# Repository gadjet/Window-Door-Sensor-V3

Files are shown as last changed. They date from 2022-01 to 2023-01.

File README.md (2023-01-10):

# Window-Door-Sensor-V3
Smaller version of version 2.
This version has the components on one side and the ESP12 Module on the other side the PCB tracks supplying the
ESP module have also been beefed up to redice the size  of the supply capacitor and I have this  running currently
without a 1000uF capacitorand it works fine but when I tested version 2 with an oscilloscope on the supply pins of
the ESP a 220uF was enough to hold the  supply during transmission above 3V.

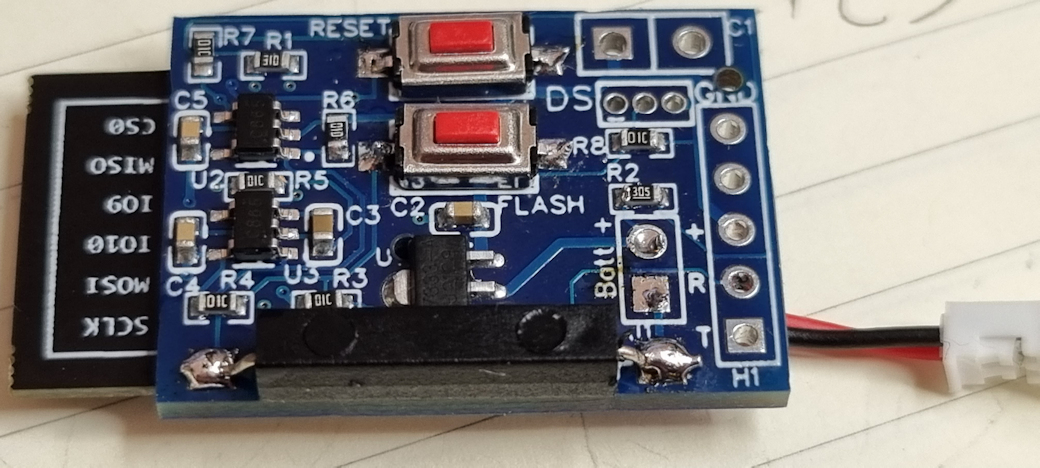
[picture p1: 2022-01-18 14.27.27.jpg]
Version 2

This version also has a DS18B20 footprint on the PCB but unfortunately I made a schoolboy error and connected the DQ
to GPIO9 which I later found out is a no-no as it's connected to the internal flash memory and accessing it causes
the ESP to crash.  If you wish to use a DS18B20 then I would cut the track to GPIO9 and run a wire from the left side
of R8 to GPIO2 on the ESP module.

If anyone is interested in buying the PCB then let  me know as I'm considering creating a Tindie store to sell
my surplus PCBs on to fund the next PCBs :-)

The code for the Sensor can be found in the earlier version

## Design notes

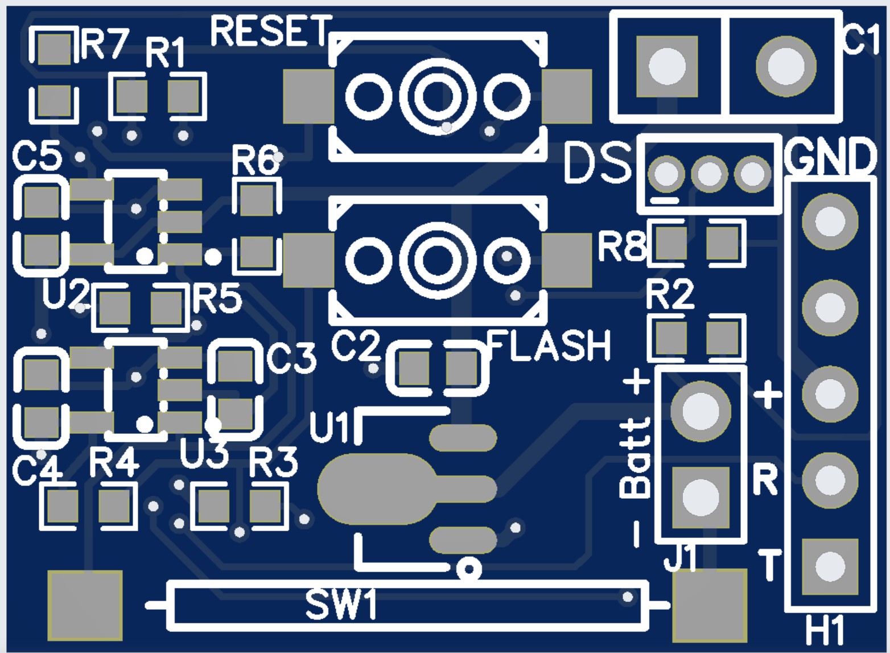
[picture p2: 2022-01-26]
V3 top.jpg

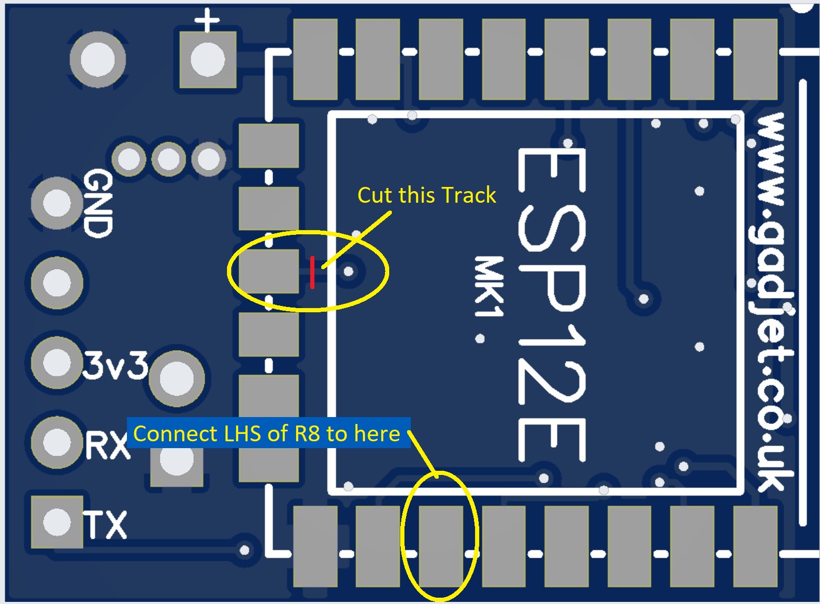
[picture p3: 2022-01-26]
V3 DS18B20 Modification.jpg

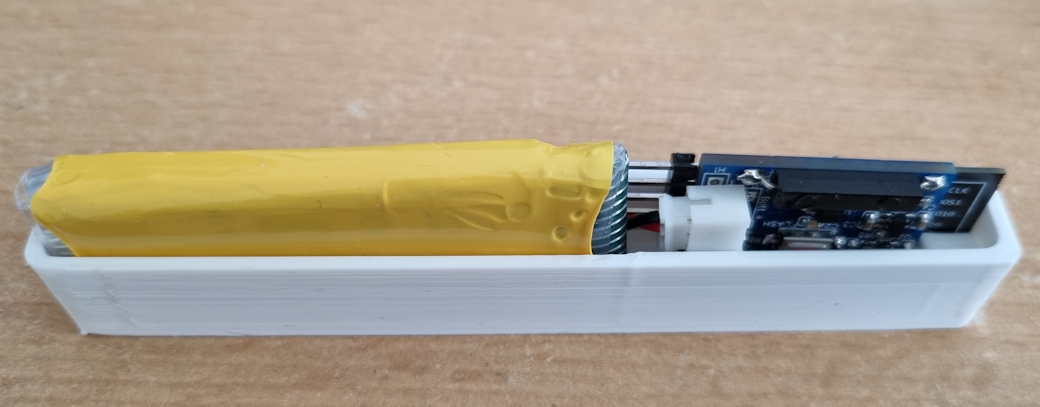
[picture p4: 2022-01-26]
2022-01-26 15.44.01.jpg

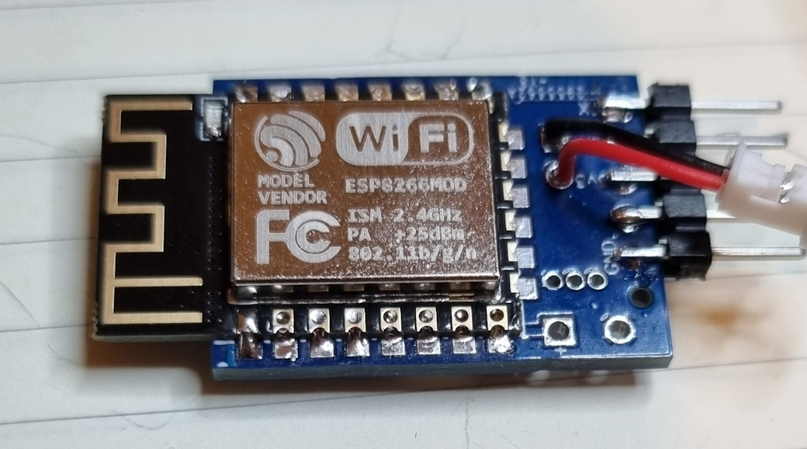
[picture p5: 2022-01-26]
2022-01-19 08.07.30.jpg

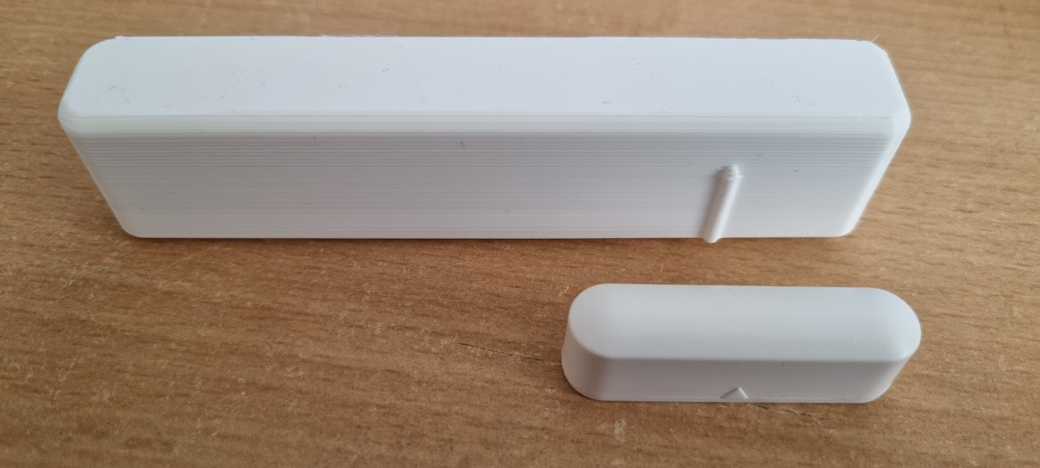
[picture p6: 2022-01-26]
2022-01-26 15.58.50.jpg

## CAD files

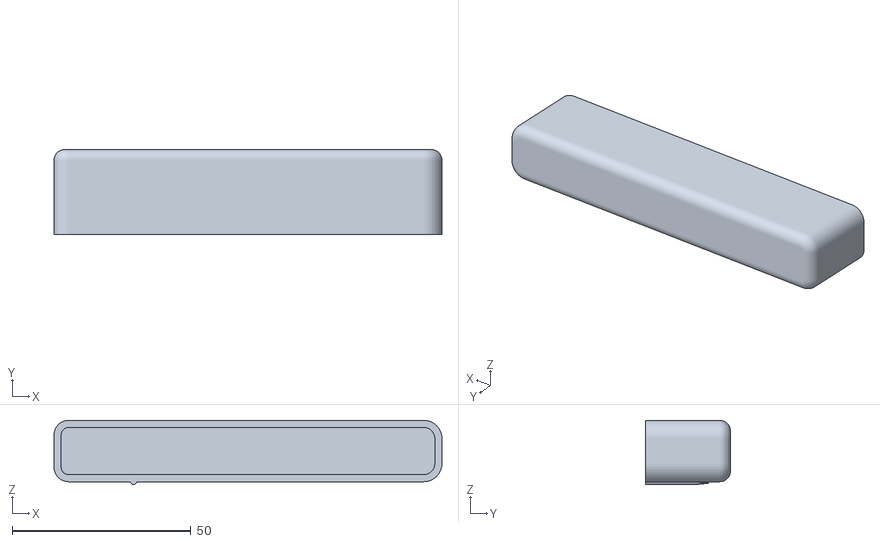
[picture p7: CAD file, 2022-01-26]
V3 Slim Top.stl
108.7 x 23.8 x 18.0

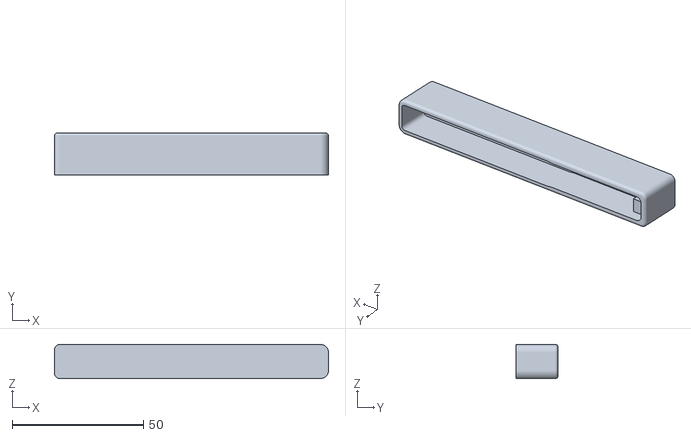
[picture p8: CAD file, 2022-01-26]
V3 Slim Bottom.stl
104.5 x 16.0 x 13.0

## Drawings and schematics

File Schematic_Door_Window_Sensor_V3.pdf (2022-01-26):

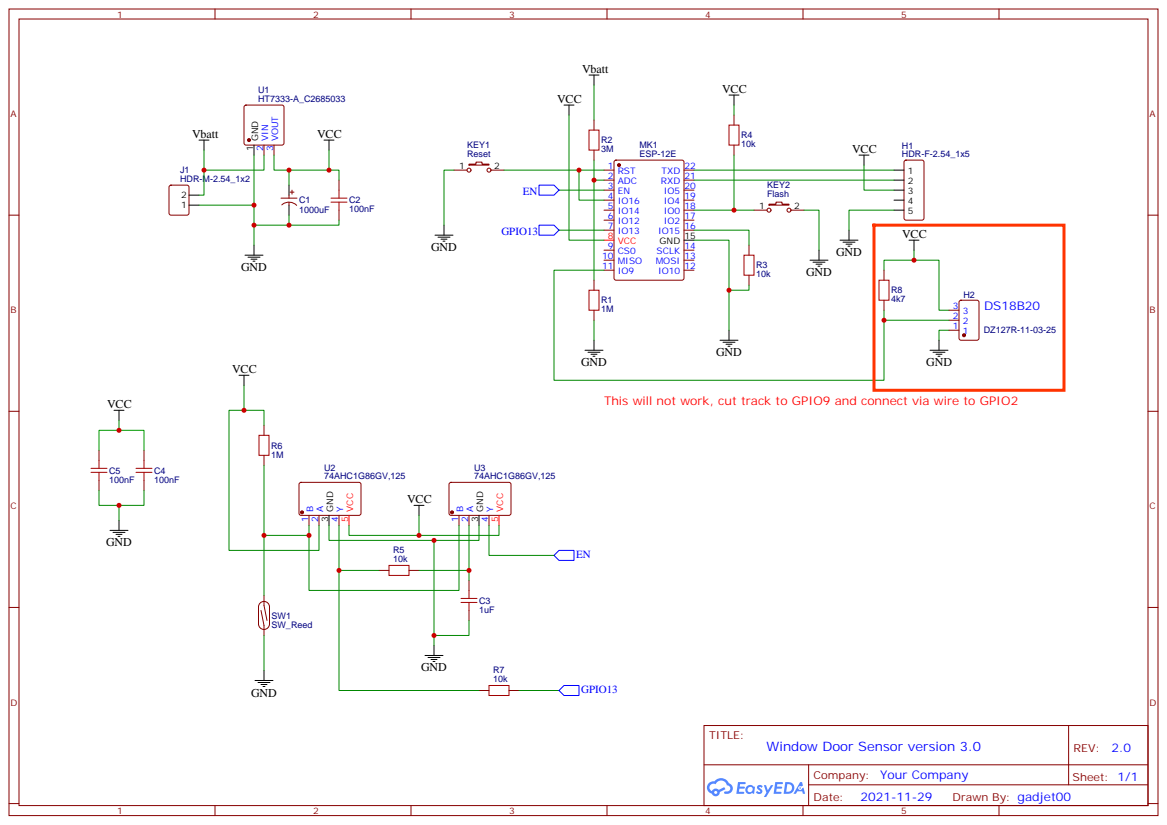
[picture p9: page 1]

This will not work, cut track to GPIO9 and connect via wire to GPIO2

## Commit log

2022-01-26 Add files via upload
    Pictures of the installation in the 3D printed enclosure
2022-01-26 Add files via upload
    Schematic PDF
2022-01-26 Add files via upload
    PCB Layouts
2022-01-26 Add files via upload
    Enclosure STL files added
    [V3 Slim Bottom.stl, V3 Slim Top.stl]
